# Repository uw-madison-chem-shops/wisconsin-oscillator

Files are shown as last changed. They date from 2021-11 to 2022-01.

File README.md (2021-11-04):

# Wisconsin Oscillator

Small, inexpensive, low power device for powering ion guiding devices.

The Wisconsin Oscillator has been published in the Journal of the American Society for Mass Spectrometry. Please read our article to learn more about the motivation behind the Wisconsin Oscillator and to see examples the circuit being used to guide ions through a custom spectrometer.

> [The Wisconsin Oscillator: A Low-Cost Circuit for Powering Ion Guides, Funnels, and Traps](https://doi.org/10.1021/jasms.1c00247) Kregel, S. J.; Thompson, B. J.; Nathanson, G. M.; and Bertram, T. H. _Journal of the Americian Socieity for Mass Spectrometry_ (2021)

## PCB

Printed circuit board fabrication files can be found in the gerber directory.
PCB images generated with [tracespace](https://github.com/tracespace/tracespace) follow.




## Bill of Materials

C1 and L1/L2 can be changed to control the amplitude and frequency of the oscillator, as described in the next section.
All other parts are listed below.

| reference | manufacturer | part number |  vendors |
| :--- | :--- | :--- | :--- |
| C2 | various | 2.2 pF ceramic, 1kV, 1206 package | [Mouser](https://www.mouser.com/ProductDetail/Walsin/1206N2R2C102CT?qs=ZrPdAQfJ6DMo6D%2FvZxBqfw%3D%3D) |
| C3, C4 | various | 4.7 nF ceramic, 1kV, 1206 package | [Mouser](https://www.mouser.com/ProductDetail/Kyocera-AVX/1206AC472MAT1A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) |
| C5 | various | 100 uF electrolytic | [Mouser](https://www.mouser.com/ProductDetail/CDE-Illinois-Capacitor/107CKE025MEM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) |
| C6 | various | 3.3 nF ceramic, 1206 package | [Mouser](https://www.mouser.com/ProductDetail/Samsung-Electro-Mechanics/CL31C332JBFNNNE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) |
| J1, J2, J3, J4 | Molex | 22-23-2021 | [Mouser](https://www.mouser.com/ProductDetail/Molex/22-23-2021?qs=%2Fha2pyFaduiHQLs56YZXs3AkvtRoBprDw5MnVZuMKr8%3D) |
| R1 | various | 6.8 kOhm, 1206 package | [Mouser](https://www.mouser.com/ProductDetail/Panasonic/ERJ-8ENF6801V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) |
| R2, R3 | varous | 1 Mohm, 1206 package | [Mouser](https://www.mouser.com/ProductDetail/Vishay-Dale/CRCW12061M00FKEAC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) |
| U1, U2, U3, U4 | TI | CD74AC04M96 | [Mouser](https://www.mouser.com/ProductDetail/Texas-Instruments/CD74AC04M96?qs=5BZzbFV4k2sxVMcJXGEnkA%3D%3D) |
| U5 | RECOM | R-78B6.5-1.0 | [Mouser](https://www.mouser.com/ProductDetail/RECOM-Power/R-78B65-10?qs=YWgezujkI1Jcc6KIi%2FUXSQ%3D%3D) |

## Choice of Inductor, Capacitor

### Capacitor C1

Here is a selection of capacitor values we have tried.
All capacitors are 1 kV 1206 package.

| value | manufacturer | part number |  vendors |
| :--- | :--- | :--- | :--- |
| 56 pF | Yageo | CC1206JKNPOCBN560 | [Mouser](https://www.mouser.com/ProductDetail/Yageo/CC1206JKNPOCBN560?qs=57cj7OiSijk2ADKKy4CU4w%3D%3D) |
| 68 pF | Yageo | CC1206JKNPOCBN680 | [Mouser](https://www.mouser.com/ProductDetail/YAGEO/CC1206JKNPOCBN680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) |
| 82 pF | Yageo | CC1206JKNPOCBN820 | [Mouser](https://www.mouser.com/ProductDetail/YAGEO/CC1206JKNPOCBN820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) |
| 100 pF | Yageo | CC1206JKNPOCBN101 | [Mouser](https://www.mouser.com/ProductDetail/YAGEO/CC1206JKNPOCBN101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) |

### Inductors L1/L2

Here is a selection of inductor values we have tried.

| value | manufacturer | part number |  vendors |
| :--- | :--- | :--- | :--- |
| 33 uH | Murata | 22R333C | [Mouser](https://www.mouser.com/ProductDetail/Murata-Power-Solutions/22R333C?qs=AG1tZYOK7s5pE%2FTYgTs9bg%3D%3D) |
| 47 uH | Murata | 22R473C | [Mouser](https://www.mouser.com/ProductDetail/Murata-Power-Solutions/22R473C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) |
| 68 uH | Murata | 22R683C | [Mouser](https://www.mouser.com/ProductDetail/Murata-Power-Solutions/22R683C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) |
| 100 uH | Murata | 22R104C | [Mouser](https://www.mouser.com/ProductDetail/Murata-Power-Solutions/22R104C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) |
| 150 uH | Murata | 22R154C | [Mouser](https://www.mouser.com/ProductDetail/Murata-Power-Solutions/22R154C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) |
| 220 uH | Murata | 22R224C | [Mouser](https://www.mouser.com/ProductDetail/Murata-Power-Solutions/22R224C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) |

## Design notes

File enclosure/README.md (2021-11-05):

# Enclosure

A simple 3D-printable enclosure for the Wisconsin Oscillator.

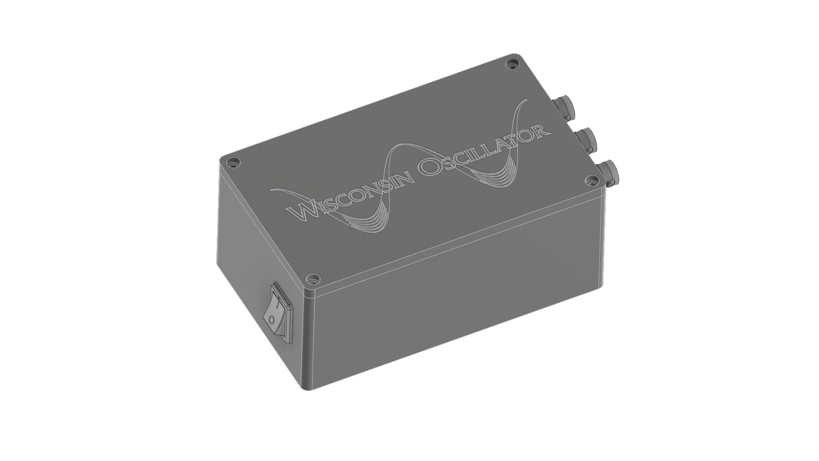
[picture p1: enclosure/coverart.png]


## Bill of Materials

All other parts are listed below.

| part (quantity) | manufacturer | part number |  vendors |
| :--- | :--- | :--- | :--- |
| BNC jack (3) | Amphenol | 031-10-RFXG1 | |
| barrel jack (1) | Switchcraft  | 722A | |
| switch (1) | E-Switch | R1973ABLKGILGF3  | |
| heat set insert (8) | McMaster | 94459A270 | |
| screw (8) | various | 1/8 inch #4-40 | |

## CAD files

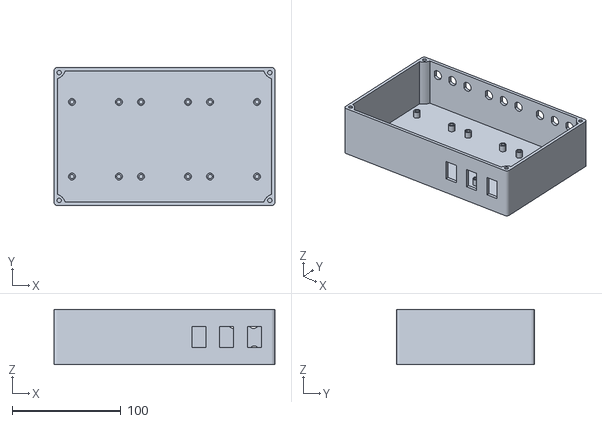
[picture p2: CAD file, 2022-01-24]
enclosure/3_Circuit_Enclosure.STL
203.2 x 127.0 x 50.8

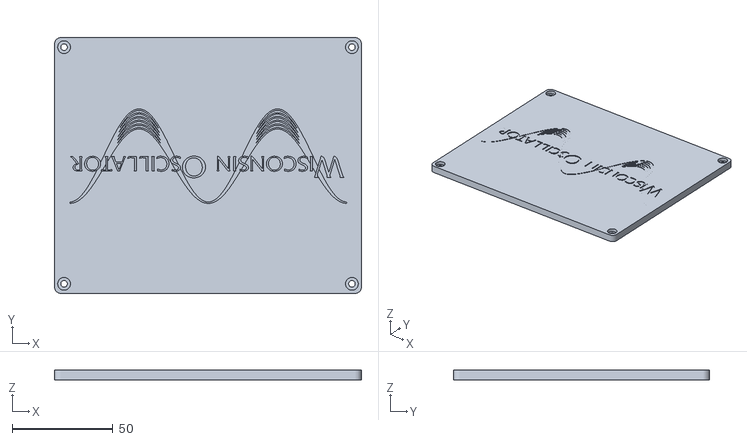
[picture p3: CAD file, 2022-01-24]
enclosure/2_Circuit_Lid.STL
152.4 x 127.0 x 4.76

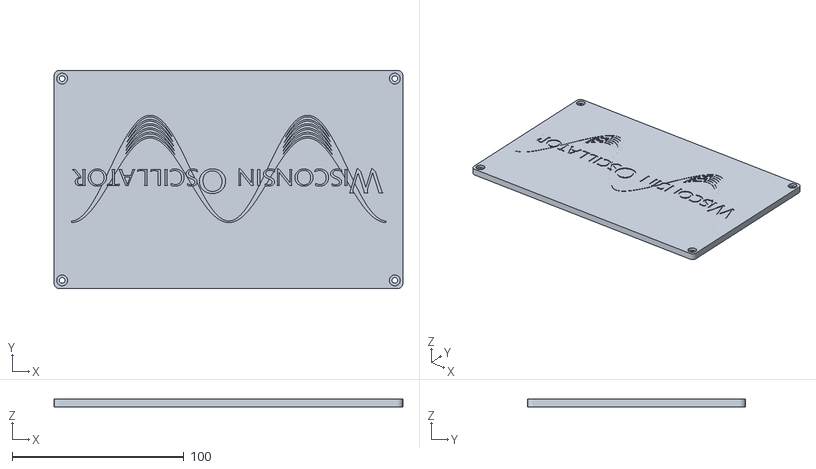
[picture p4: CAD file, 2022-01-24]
enclosure/3_Circuit_Lid.STL
203.2 x 127.0 x 4.76

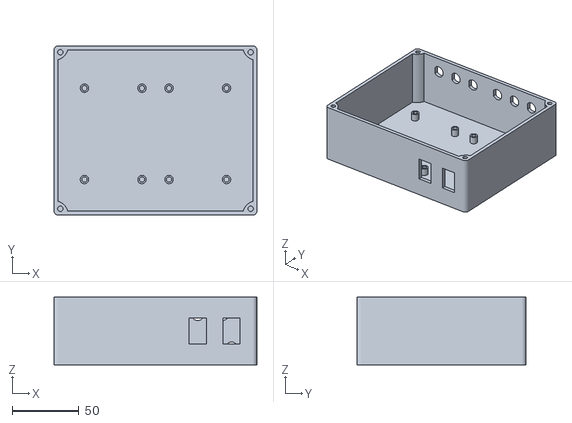
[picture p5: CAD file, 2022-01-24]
enclosure/2_Circuit_Enclosure.STL
152.4 x 127.0 x 50.8

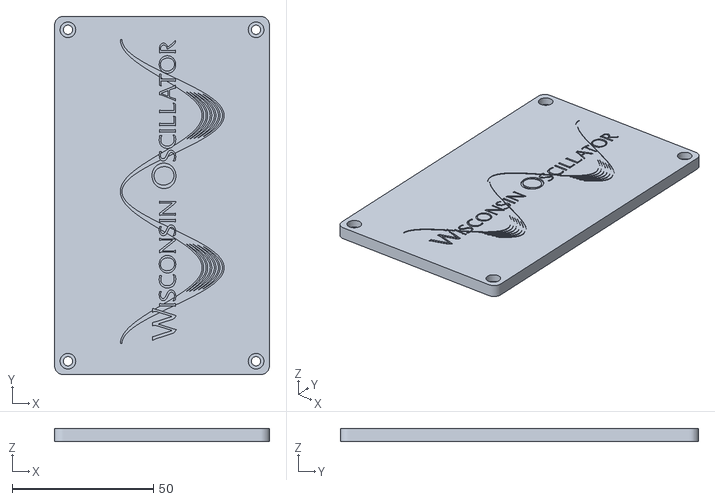
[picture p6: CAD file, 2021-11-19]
enclosure/Lid_SW_Logo.STL
76.2 x 127.0 x 4.76

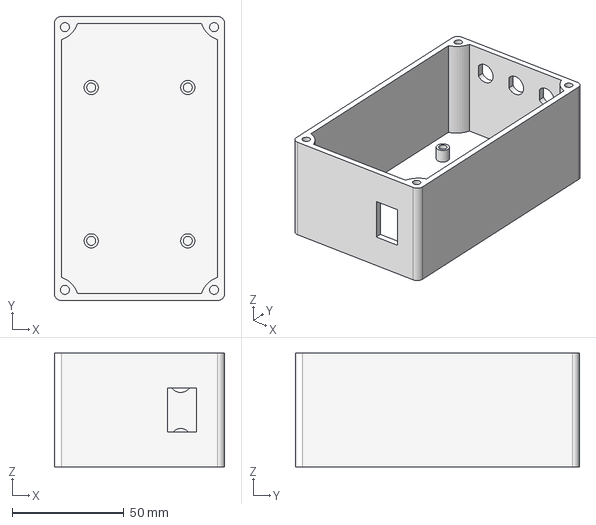
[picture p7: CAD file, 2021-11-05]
enclosure/1_Circuit_Enclosure.stp
76.2 x 127.0 x 50.8 mm

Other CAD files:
enclosure/Single_Circuit_Box.stl

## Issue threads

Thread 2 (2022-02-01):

observations from Amber

untzag, 2022-02-01:
The discrepancies between the current PCB image up on github versus the table are:

C3 appears in the table but not on the image.
C5 is 4700pF ceramic in image but 100 UF electrolytic in table.
C6 is 100 uF electrolytic in image but 3.3 nF ceramic in table.
C7 appears in the image but not on the table.

The board I have for the oscillator is the June 2021 version, so as expected, it is a different version than the one that is up on github. The difference with the board I have currently is that there is a spot for C3 printed, and it is a 2pF ceramic capacitor matching C2. I think the only other thing is that my C6 value is not printed on my board.

dibyashap, 2023-03-11:
We are trying to make one of this oscillator. I had few questions.
1. CD74AC04M96 is out of stock now on the distributor's site. Is there any alternative for this device?
2. why did you assemble three of them? is one nor suffice?
3.  The ion funnel that we have has resistive load along with capacitive. will it still work? I am attaching the ion funnel design, let me know if you have any comments on that
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

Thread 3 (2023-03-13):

We are trying to make one of this oscillator. I had few questions.

untzag, 2023-03-13:
We are trying to make one of this oscillator. I had few questions.
1. CD74AC04M96 is out of stock now on the distributor's site. Is there any alternative for this device?
2. why did you assemble three of them? is one nor suffice?
3.  The ion funnel that we have has resistive load along with capacitive. will it still work? I am attaching the ion funnel design, let me know if you have any comments on that
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

_Originally posted by @dibyashap in https://github.com/uw-madison-chem-shops/wisconsin-oscillator/issues/2#issuecomment-1464835219_

untzag, 2023-03-13:
> CD74AC04M96 is out of stock now on the distributor's site. Is there any alternative for this device?

That's frustrating, I didn't realize that. Perhaps MC74AC04DR2G? @sjkregel might have other ideas.

> why did you assemble three of them? is one nor suffice?

Quoting from the paper: The three inverters in series serve to increase the gain, enabling the circuit to more rapidly reach its
equilibrium operating condition compared to a feedback oscillator comprising a single inverter

> The ion funnel that we have has resistive load along with capacitive. will it still work? I am attaching the ion funnel design, let me know if you have any comments on that

So basically you're loading down the oscillator with thirteen 100k resistors in parallel (effective resistance ~8k). You're also adding a lot of capacitance. @sjkregel did you ever try to drive your funnel?

> It'd be great if you can make one and ship to us.(Location: India)

Probably not. It's very hard to pay for things across institutional boarders.

> Also please let us know if you have updated any parts.

Not that I know of.

sjkregel, 2023-03-13:
To add on to what @untzag said above,

1) I haven't looked too much at other options for inverters. The key factors are the current source and sink (needs to be large), and the propagation delay (needs to be small). The CD74AC04M96 is nice in that they have these features along with a wide operating voltage range.

2) We assembled three oscillator circuits to drive three separate ion guides.

3) A resistive load in general isnt a problem, however your effective resistance of 8kOhm likely is. You may want to think about re-arranging your resistive network so that each polarity of RF is resistivally isolated. IE each + electrode is only resistivally coupled to other + electrodes, and the same for the - electrodes. In this case you would have two resistive ladders, which can be offset by adding R/2 value resistors on the ends. Alternatively you can simply increase the resistor values you're using. Using 1MOhm instead of 100kOhm will increase your effective resistance to 80kOhm, which is probably ok.

As far as your capacitive load goes, it looks to me like you're using the 3.3nF capacitors as decoupling capacitors in a similar manner to C3 and C4 in the paper. This shouldn't cause you any problems.

4) Same as above.

5) We haven't updated any designs as of yet, but I'm working on incorporating amplitude control into the output RF waveform. Hopefully that board will be on the github in the next month or so.

dibyashap, 2023-03-14:
> 5. We haven't updated any designs as of yet, but I'm working on incorporating amplitude control into the output RF waveform. Hopefully that board will be on the github in the next month or so.
We can use a variable DC supply to provide amplitude control ,right?

dibyashap, 2023-03-14:
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

We can use a variable DC supply to provide amplitude control ,right?

dibyashap, 2023-03-14:
> 5. We haven't updated any designs as of yet, but I'm working on incorporating amplitude control into the output RF waveform. Hopefully that board will be on the github in the next month or so.

We can use a variable DC supply to provide amplitude control ,right? as ypu have mentioned in the paper?

dibyashap, 2023-06-06:
did you upload the design that you talked about in the above?

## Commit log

2021-11-05 stl files
    [Lid_SW_Logo.STL, Single_Circuit_Box.stl]
2021-11-19 new lid
    [Lid_SW_Logo.STL]
2022-01-24 Added STL files for 2 and 3 circuit enclosures.
    When constructing enclosures using 2 or 3 circuits, additional hardware (BNC connections, Switches, etc....) are needed to provide the necessary connections.
    [2_Circuit_Enclosure.STL, 2_Circuit_Lid.STL, 3_Circuit_Enclosure.STL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]
